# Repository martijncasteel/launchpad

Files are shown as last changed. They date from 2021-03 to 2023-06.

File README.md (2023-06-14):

# push-to-talk
A simple macro keyboard designed for using USB HID protocol.

> Unfortantly I was not able to get the device working as intended. There is nothing wrong with the hardware or the code, it is just something I want I can't do without getting a certification with Microsoft. I did learn a lot, plugging in a USB device will never be the same!

My approach is to use the USB HID protocol in full and specifically the USB HID Telephone pages. The goal is to mute and unmute the microphone on Teams on a laptop, even when teams is not in focus.

```
 BTN0  - flash, end call
 BTN1  - camera toggle on/off
 BTN2  - volume increment
 BTN3  - volume decrement
 BTN4  - volume mute
 BTN5  - microphone mute toggle
 BTN6  - Hold to unmute microphone
```

This repository contains the entire project, [/pcb](https://github.com/martijncasteel/launchpad/tree/main/pcb) contains the schematics and design of the board. I used [Kicad](https://www.kicad.org/) for this. The gerber files and other nessecities for manufacturing are located in the [/assembly](https://github.com/martijncasteel/launchpad/tree/main/assembly) folder.

The board is designed to have six regular 1u keycaps, and one 2u keycap. All use regular cherry mx key switches. The board has an ATmega32u4 with native usb support. The ICSP connector can be used to flash the microcontroller. 

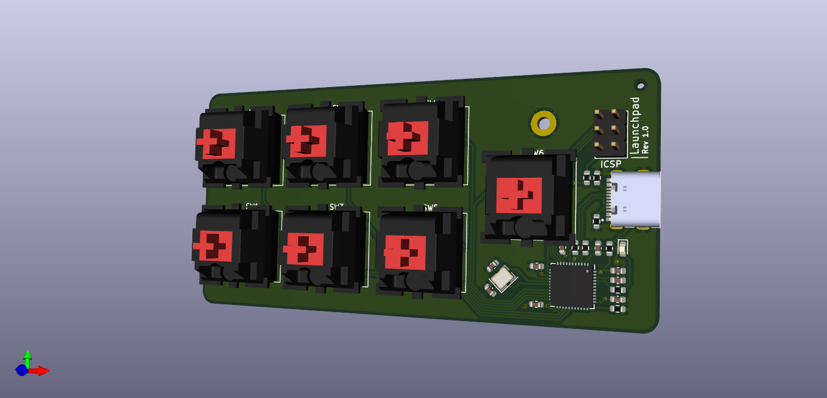
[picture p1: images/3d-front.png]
3D render


The [software](https://github.com/martijncasteel/launchpad/tree/main/code) is written in C and built using avr-gcc. Using avrdude you can flash the microcontroller as well as setting some fuses. In my search on how other have done this, I haven't found a lot of sources on lowlevel programming with USB. To help you further along I added loads of comments. 

<br /><br /><!-- spacing for header -->

## My story so far
During my study I did a lot of software engineering but never went further than using arduino's. So my goal was to learn more about hardware. A lot of youtube videos brought me so far. [Ben Eater](https://youtu.be/wdgULBpRoXk) has some great videos explaining the USB protocol. [Mitch Davis](https://youtu.be/Q2DakPocvfs) goes into more detail about programming Atmega microcontrollers.

Using schematics from arduino I was able to create a schematic quite easily. Of course, also looked at the datasheets to have a better understanding.

After creating the [assembly](https://github.com/martijncasteel/launchpad/tree/main/assembly), I uploaded the files to a pcb manufactorer and also let them populate the board. I had some issues with the USB port since the wrong one was in the BOM. Finally I started [coding](https://github.com/martijncasteel/launchpad/tree/main/code), at first with the arduino IDE. But quickly realised that I wanted to do it from scratch. Down the rabbit hole, I went!

<br /><br /><!-- spacing for header -->

## Where I am now
Well, the hardware went back in a drawer, I'm updating my README and that's it I guess. The buttons declared in the normal consumer control are working; volume up/down, and mute. The toggle camera is somewhat working, however teams just freezes the last frame and is not able to recover from it. More about the implementation in the [code](https://github.com/martijncasteel/launchpad/tree/main/code) directory.

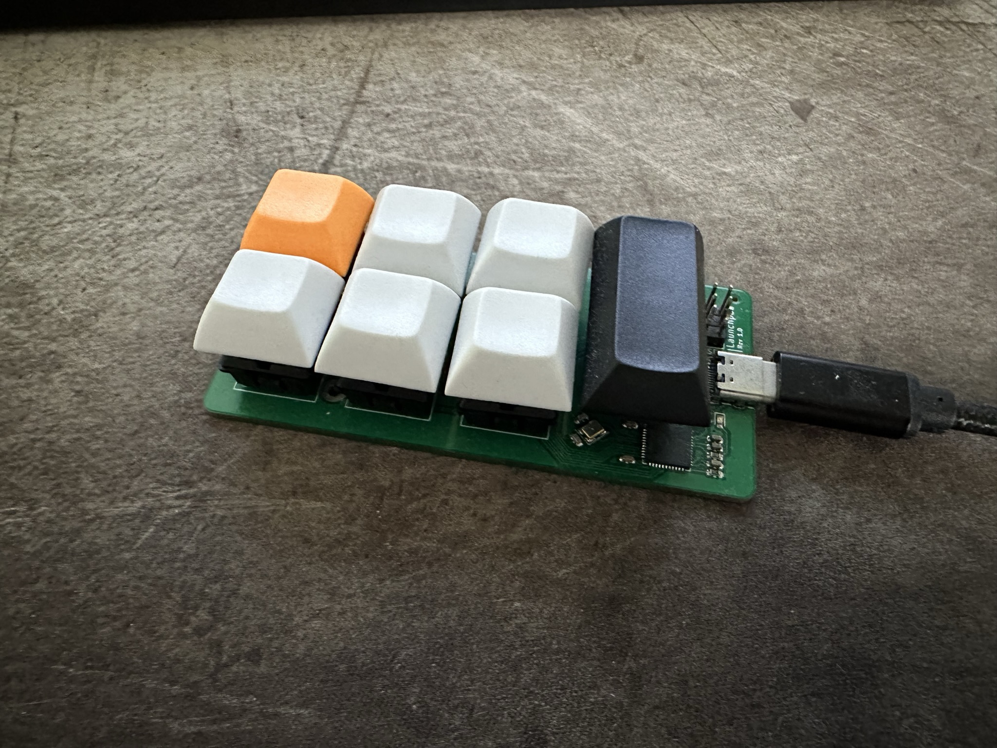
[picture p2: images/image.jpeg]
Launchpad photo


The buttons for the telephone page; mute microphone and flash are not working. The computer receives the commands fine but not actions is take by the OS or teams. It did cross my mind to implement it as a [generic keyboard](https://github.com/martijncasteel/launchpad/commit/3572334c3c04b70ffb8cd755422ddb2e0c5258f0) and use the teams shortcuts. The whole purpose was to be able to mute microsoft without having it in focus, so I scratched that idea. But it will work

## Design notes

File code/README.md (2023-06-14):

# push-to-talk - code

In this README the code directory is explained in more detail. 

## setting up dev environment

```bash
sudo apt update
sudo apt install binutils gcc-avr avr-libc avrdude make
```

The [binary](https://github.com/martijncasteel/launchpad/tree/main/code/bin) can be flashed on the board using the Makefile. The code is far from perfect, and there might be plenty of improvements, feel free to add a pull request! 

```bash
# built intermediates in /build and binary in /bin
# note; changes in header files are not picked up, use make clean
make

# flash to microcontroller
# note; /dev/ttyUSB0 is also the default port, argument can be omitted
make flash PORT=/dev/ttyUSB0

# set fuses on microcontroller
make fuses PORT=/dev/ttyUSB0

# remove intermediates and binary
make clean
```

<br /><!-- spacing for header -->

## USB HID Telephone pages
This approach uses a custom report descriptor defined in [usb.h](https://github.com/martijncasteel/launchpad/tree/main/code/include/usb.h) which is mapped on the pins used by the buttons. For the bigger button, there is some additional code to set either one of the two least significant bits. When the button is pressed the microphone is unmuted, when released the microphone is muted. 

There are more buttons to toggle to mute the microphone and a button to mute the speakers. There are two buttons to increase or decrease the volume, and also a button to hang up the phone. The complete button map is described in [board.h](https://github.com/martijncasteel/launchpad/tree/main/code/include/board.h)

> This is my preferred implementation, it is pretty neat. Unfortunately, it is not working yet since Teams is not supporting the USB HID Telephone pages.
> Microsoft has chosen to only allow certified paying manufacturers to create integrated hardware.

In trying to get it to work I have now created multiple reports with their own report id. Windows works better with volume control in a separate consumer control collection. Windows is also very picky in the byte alignment, you must add padding to get full bytes, otherwise Windows will throw an urb_fuction_abort error.

As a last resort I tried a new feature called [call state management control](https://www.usb.org/sites/default/files/hutrr106-callstatemanagementcontrol_0.pdf). It was actually submitted by Microsoft to the USB organisation and added to the HUT pages. Unfortunatly I wasn't working for me. But I suspect It could be do to my managed laptop. I did not save the code, but there is a nice example in the link above.

<br /><!-- spacing for header -->

## Debugging
After watching loads of [Ben Eater](https://www.youtube.com/watch?v=2lPzTU-3ONI) videos I used a [usb capture](https://wiki.wireshark.org/CaptureSetup/USB) extension for Wireshark. This allowed me to see the communication and the setup progress. There you'll find the first hints why stuff isn't working. In Windows the device manager can give you some more hints, especially the byte alignment is mentioned here, Linux doesn't throw an error if the alignment is off. In my board I did not include any pins for debugging using a wire protocol. This might it a bit tricky in the beginnen but with the single led I made it work.

<br /><!-- spacing for header -->

## Documentation
In [/docs](/martijncasteel/launchpad/tree/main/code/docs) there are several relevant files for using USB HID and the ATMega32u4 microcontroller. Furthermore, there are some links below that have some more information
* https://docs.rs/atmega32u4/0.1.2/atmega32u4/usb/struct.UEINTX.html
* https://ww1.microchip.com/downloads/en/devicedoc/atmel-7766-8-bit-avr-atmega16u4-32u4_datasheet.pdf
* https://github.com/kmani314/ATMega32u4-HID-Keyboard

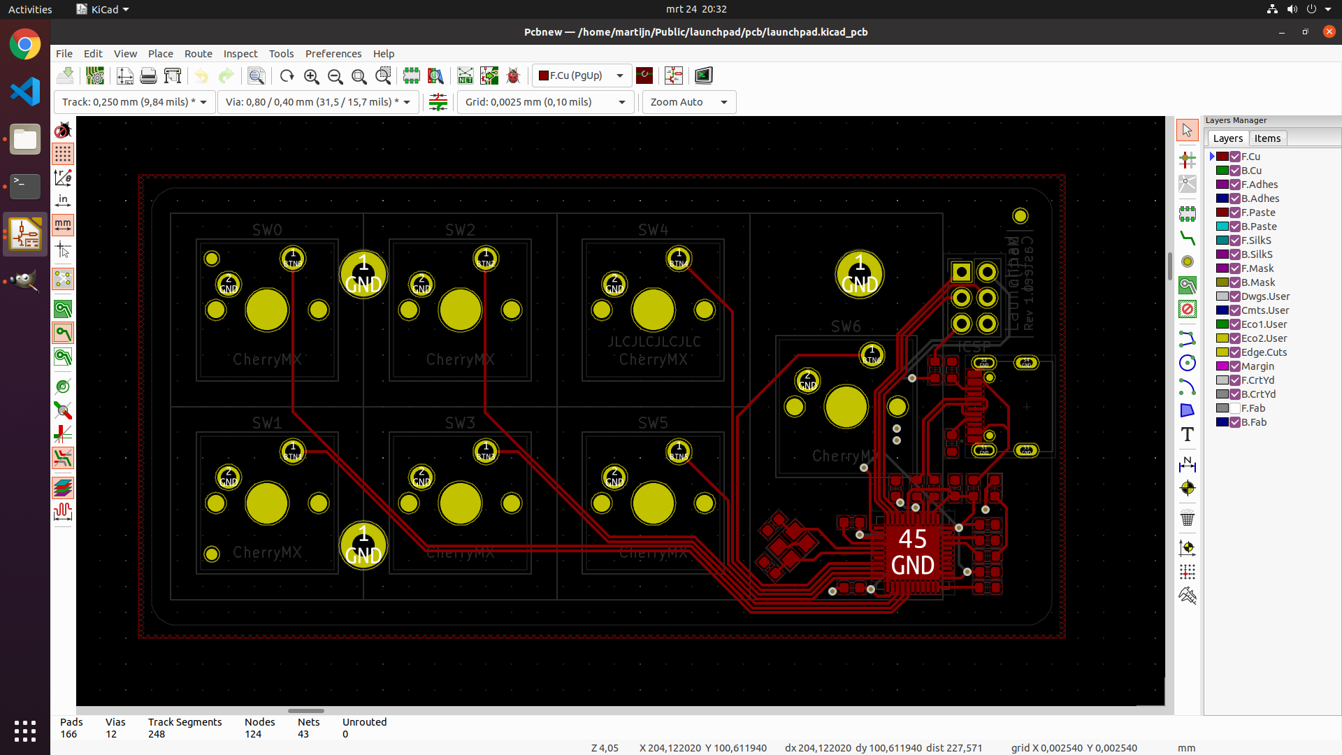
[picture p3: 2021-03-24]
images/f-cu.png

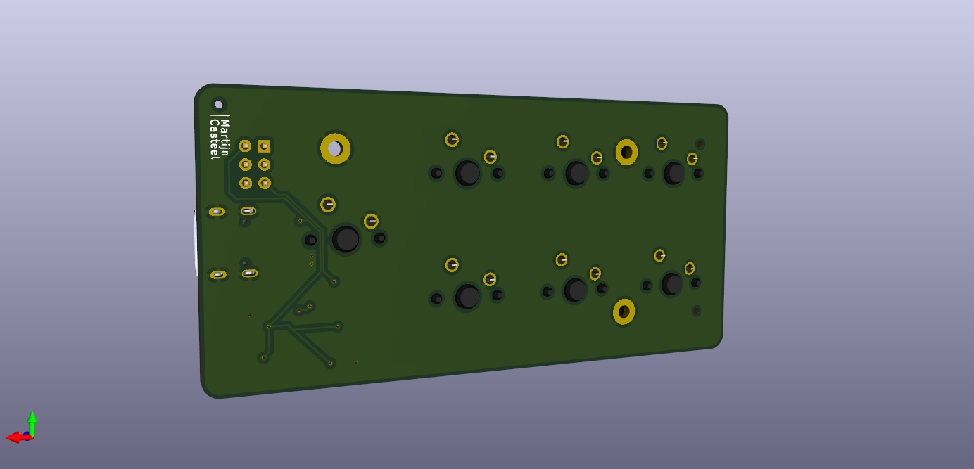
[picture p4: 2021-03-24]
images/3d-back.png

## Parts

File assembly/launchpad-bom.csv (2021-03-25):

Comment | Designator | Footprint | LCSC
1uF | C2 | Capacitor_SMD:C_0603_1608Metric | C15849
0.1uF | C1,C3,C4,C5,C6 | Capacitor_SMD:C_0603_1608Metric | C14663
10uF | C7 | Capacitor_SMD:C_0603_1608Metric | C19702
22pF | C8,C9 | Capacitor_SMD:C_0603_1608Metric | C1653
RED | D2 | LED_SMD:LED_0603_1608Metric | C2286
500mA | F1 | Fuse:Fuse_0603_1608Metric | C261937
TYPE-C-31-M-12 | J1 | Custom:HRO_TYPE-C-31-M-12 | C165948
ICSP | J2 | Connector_PinHeader_2.54mm:PinHeader_2x03_P2.54mm_Vertical
22 | R2,R3 | Resistor_SMD:R_0603_1608Metric | C23345
10K | R1,R4 | Resistor_SMD:R_0603_1608Metric | C25804
1K | R5 | Resistor_SMD:R_0603_1608Metric | C21190
5.1K | R6,R7 | Resistor_SMD:R_0603_1608Metric | C23186
CherryMX | SW0,SW1,SW2,SW3,SW4,SW5 | Button_Switch_Keyboard:SW_Cherry_MX_1.00u_PCB
CherryMX | SW6 | Custom:SW_Cherry_MX_2.00u_Vertical_PCB_unsupported
ATmega32U4-MUR | U1 | Package_DFN_QFN:QFN-44-1EP_7x7mm_P0.5mm_EP5.2x5.2mm | C45874
Crystal_GND24_Small | Y1 | Crystal:Crystal_SMD_3225-4Pin_3.2x2.5mm | C13738

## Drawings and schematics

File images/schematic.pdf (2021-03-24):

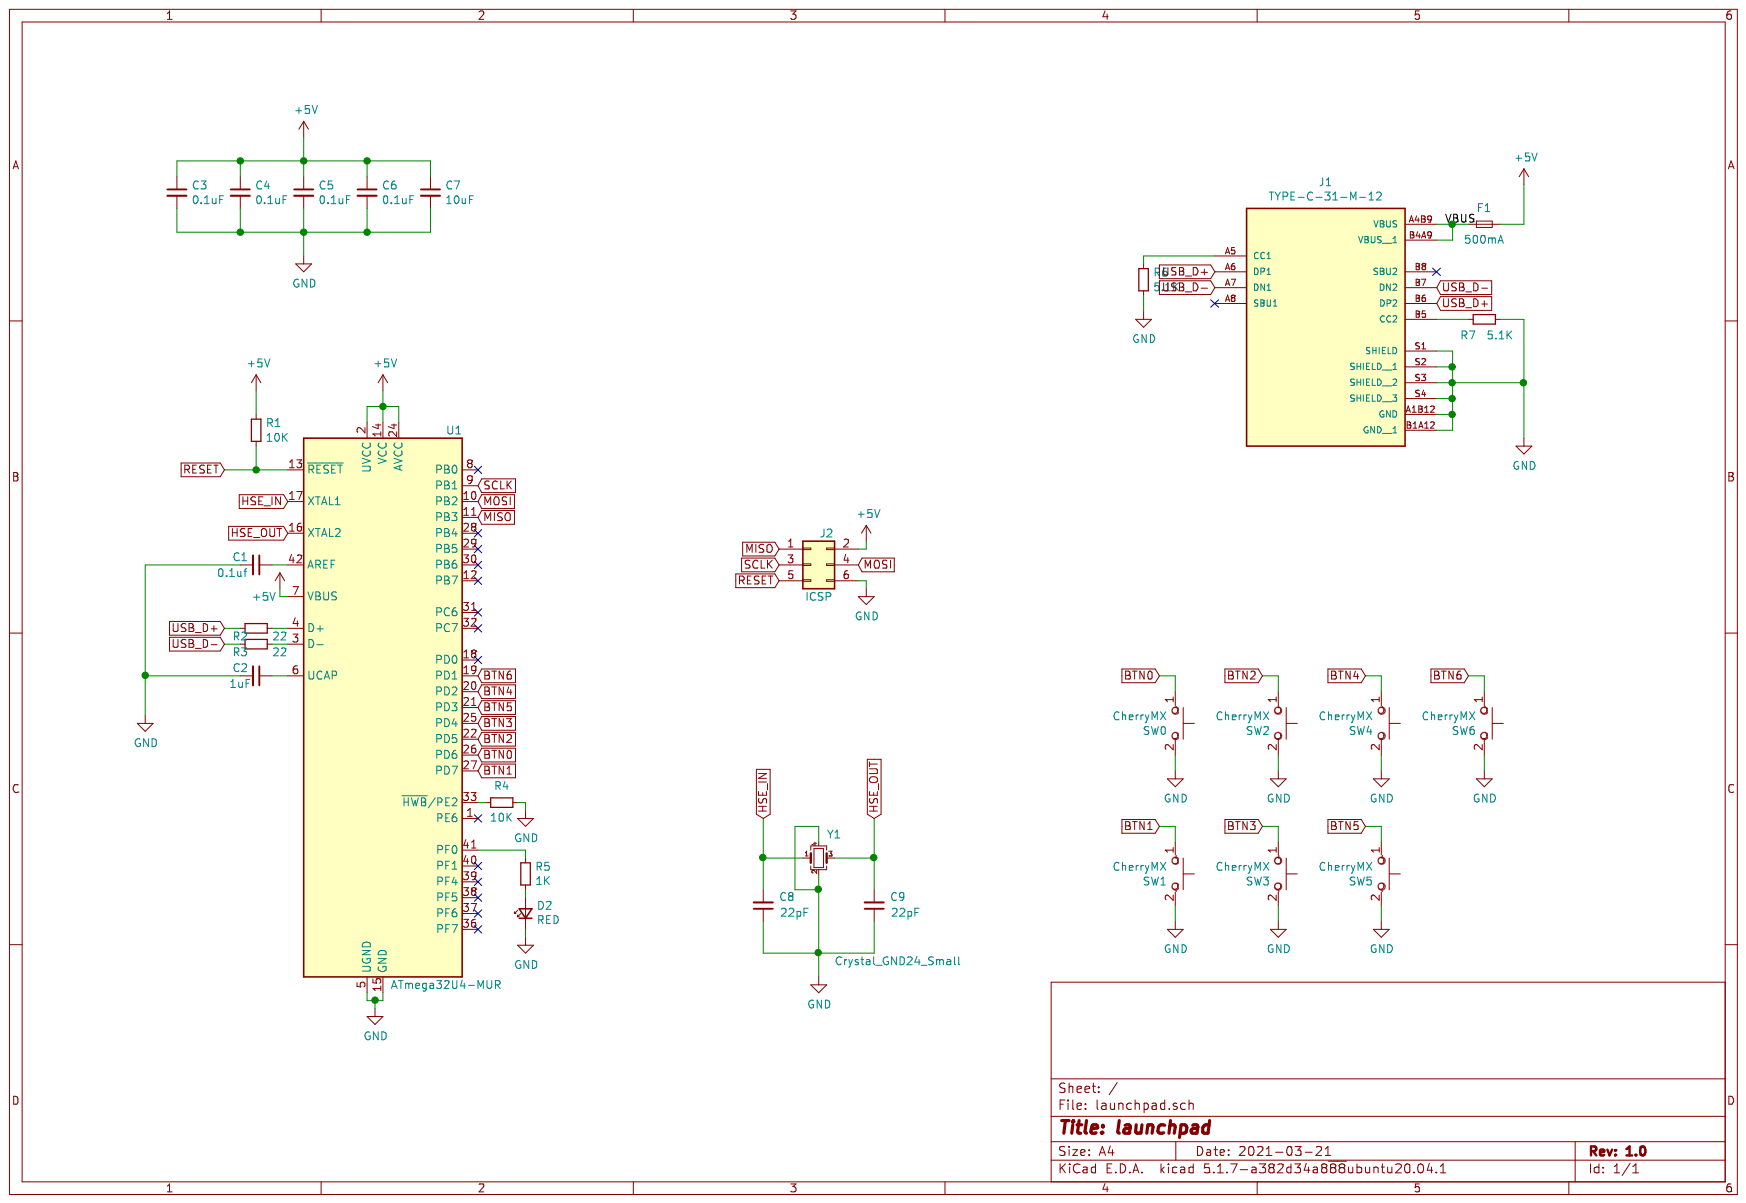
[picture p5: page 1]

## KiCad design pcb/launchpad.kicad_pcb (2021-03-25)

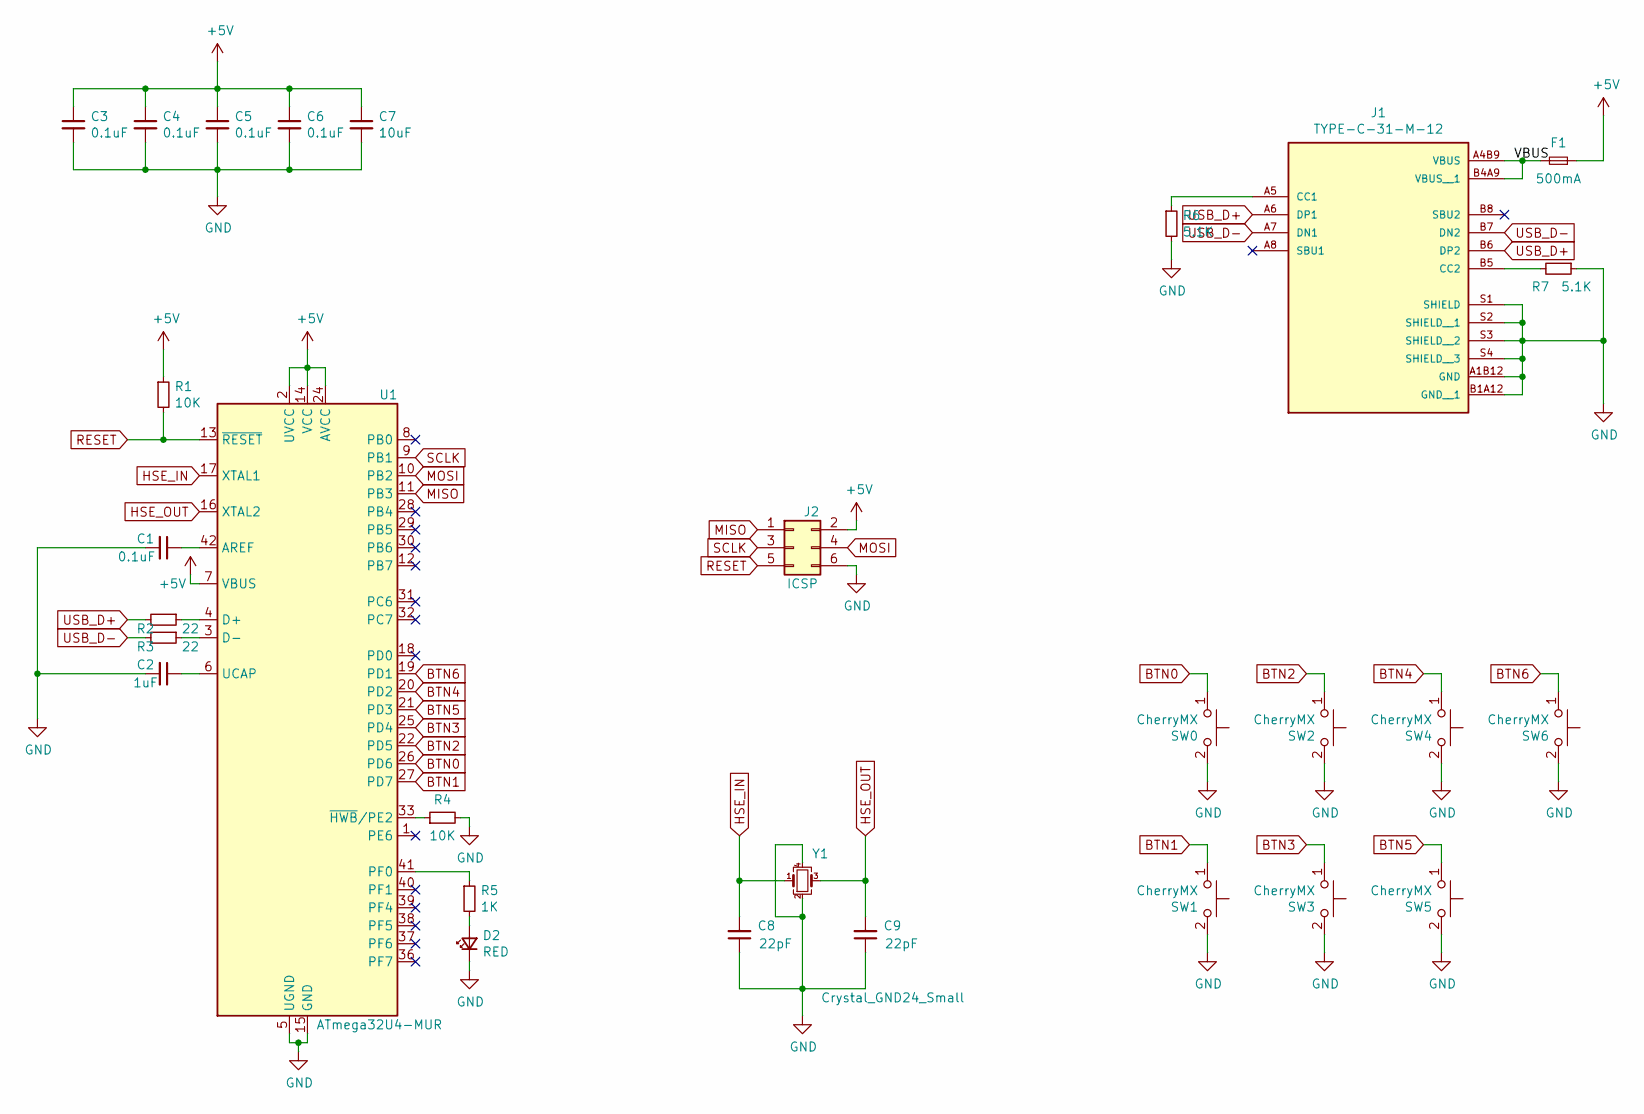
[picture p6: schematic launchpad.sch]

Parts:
C1, C3, C4, C5, C6: 0.1uF; C_0603_1608Metric; LCSC C14663
C2: 1uF; C_0603_1608Metric; LCSC C15849
C7: 10uF; C_0603_1608Metric; LCSC C19702
C8, C9: 22pF; C_0603_1608Metric; LCSC C1653
D2: RED; LED_0603_1608Metric; LCSC C2286
F1: 500mA; Fuse_0603_1608Metric; LCSC C261937
J1: TYPE-C-31-M-12; HRO_TYPE-C-31-M-12; PARTREV A; LCSC C165948
J2: ICSP; PinHeader_2x03_P2.54mm_Vertical
R1, R4: 10K; R_0603_1608Metric; LCSC C25804
R2, R3: 22; R_0603_1608Metric; LCSC C23345
R5: 1K; R_0603_1608Metric; LCSC C21190
R6, R7: 5.1K; R_0603_1608Metric; LCSC C23186
SW0, SW1, SW2, SW3, SW4, SW5: CherryMX; SW_Cherry_MX_1.00u_PCB
SW6: CherryMX; SW_Cherry_MX_2.00u_Vertical_PCB_unsupported
U1: ATmega32U4-MUR; QFN-44-1EP_7x7mm_P0.5mm_EP5.2x5.2mm; LCSC Part # C45874
Y1: Crystal_GND24_Small; Crystal_SMD_3225-4Pin_3.2x2.5mm; LCSC C13738

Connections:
+5V: C3.1, C4.1, C5.1, C6.1, C7.1, F1.1, J2.2, R1.1, U1.2 (UVCC), U1.7 (VBUS), U1.14 (VCC), U1.24 (AVCC), U1.34 (VCC), U1.44 (AVCC)
/VBUS: F1.2, J1.A4B9 (VBUS), J1.B4A9 (VBUS__1)
BTN0: SW0.1, U1.26 (PD6)
BTN1: SW1.1, U1.27 (PD7)
BTN2: SW2.1, U1.22 (PD5)
BTN3: SW3.1, U1.25 (PD4)
BTN4: SW4.1, U1.20 (PD2)
BTN5: SW5.1, U1.21 (PD3)
BTN6: SW6.1, U1.19 (PD1)
GND: C1.2, C2.2, C3.2, C4.2, C5.2, C6.2, C7.2, C8.1, C9.1, D2.1 (K), J1.A1B12 (GND), J1.B1A12 (GND__1), J1.S1 (SHIELD), J1.S2 (SHIELD__1), J1.S3 (SHIELD__2), J1.S4 (SHIELD__3), J2.6, R4.2, R6.2, R7.1, SW0.2, SW1.2, SW2.2, SW3.2, SW4.2, SW5.2, SW6.2, U1.5 (UGND), U1.15 (GND), U1.23 (GND), U1.35 (GND), U1.43 (GND), U1.45 (GND), Y1.2, Y1.4; also elsewhere on the board
HSE_IN: C8.2, U1.17 (XTAL1), Y1.1
HSE_OUT: C9.2, U1.16 (XTAL2), Y1.3
MISO: J2.1, U1.11 (PB3)
MOSI: J2.4, U1.10 (PB2)
unnamed: C1.1, U1.42 (AREF)
unnamed: C2.1, U1.6 (UCAP)
unnamed: D2.2 (A), R5.2
unnamed: J1.A5 (CC1), R6.1
unnamed: J1.B5 (CC2), R7.2
unnamed: R2.1, U1.4 (D+)
unnamed: R3.1, U1.3 (D-)
unnamed: R4.1, U1.33 (~HWB~/PE2)
unnamed: R5.1, U1.41 (PF0)
RESET: J2.5, R1.2, U1.13 (~RESET)
SCLK: J2.3, U1.9 (PB1)
USB_D+: J1.A6 (DP1), J1.B6 (DP2), R2.2
USB_D-: J1.A7 (DN1), J1.B7 (DN2), R3.2

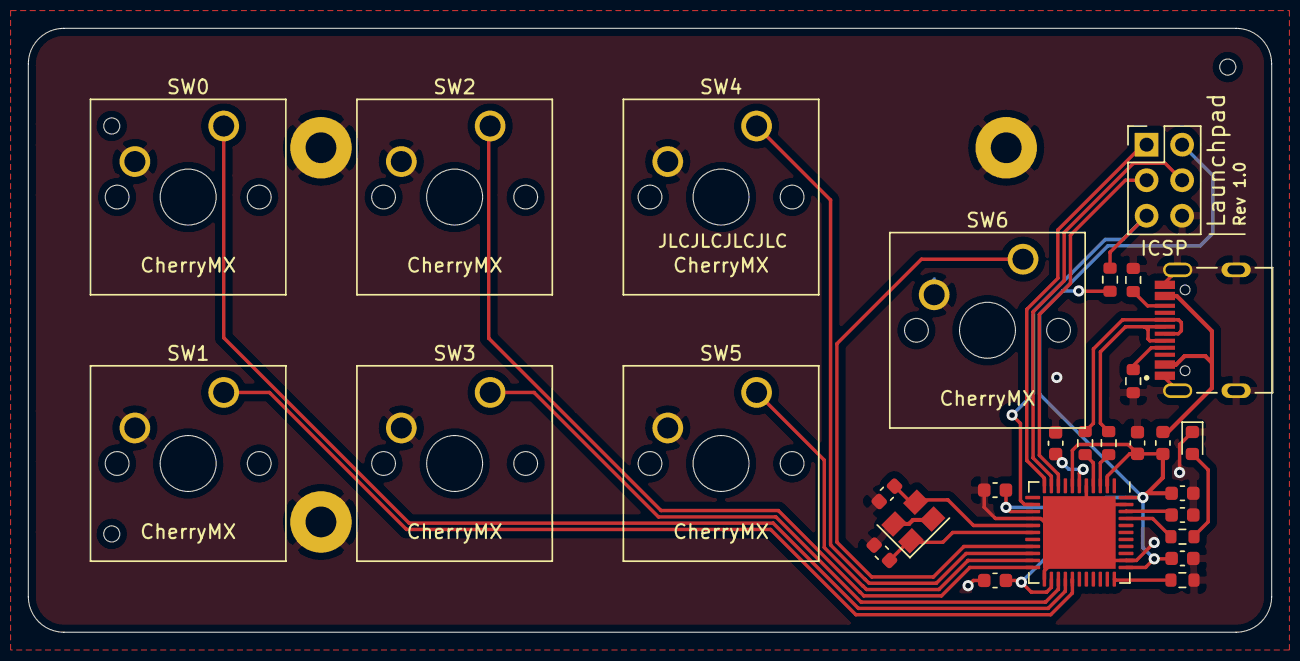
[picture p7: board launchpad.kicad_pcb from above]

Board: 2 copper layers, 88.9 x 43.2 mm, 32 parts (0 on the bottom side), 27 nets.

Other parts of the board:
H1, H2, H3: MountingHole_Pad; MountingHole_2.2mm_M2_Pad

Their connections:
GND: H1.1, H2.1, H3.1; also elsewhere on the board

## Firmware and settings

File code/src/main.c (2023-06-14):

/**
 * @name launchpad
 * @file main.c
 * 
 * @brief Mini keypad acts a usb hid device to control default functions
 * @link https://github.com/martijncasteel/launchpad
 * 
 * During covid I wanted to mute my mic with a simple key press. Unfortunatly I
 * am not allowed to write own drivers to solve this problem on the computer side.
 * 
 * Next to that I found it very interesting to design and use a custom pcb made 
 * somewhere in china. I learned lots of stuff doing this project such as pcb design,
 * revisited c and started using avr-gcc and avrdude. Ben Eater had some cool videos
 * about the USB protocol and learned lots on USB as well. 
 * 
 * Let's say, plugging in a USB device will never be the same! 
 * 
 * @author Martijn Casteel
 * @date 2022-12-22
 */

#define __ATmega32U4__
#define F_CPU 16000000UL

#include "board.h"
#include "usb.h"

#include <avr/io.h>
#include <util/delay.h>

int main()
{

  PORTD = 0xff;                 // pull up resistors, low is pressed
  DDRD &= 0x00;                 // data direction to read of PORTD
  
  DDRF |= (1 << LED);           // Make pin 23 / PORTF0 be an output

  data_t* data = usb_init();  // initialize usb connection
  uint8_t counter = 0;          // counter to check buttons once every 50 ms

  while(1) {

    if (counter % 50 == 0) {
      check_buttons(&(data->dout));
      counter = 0;
    }

    // control led
    animate_led(&(data->din));
    
    counter++;
    _delay_ms(1); 
  }

  return 0;
}

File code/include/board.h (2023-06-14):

/**
 * @file board.h
 * @brief Header file contains the layout of the board
 * 
 * @author Martijn Casteel
 * @date 2022-12-22
*/

#include <avr/io.h>

#ifndef BOARD_H
#define BOARD_H

/**
 * Layout of the board, all buttons are connected to the D 
 * register (PORTD). Should have made this mapping way 
 * simpler, revision 2 perhaps?
 * 
 * There is a single led on PORTF0.
 * 
 *  +------+------+------+------+
 *  | BTN0 | BTN2 | BTN4 |      |
 *  +------+------+------+ BTN6 |
 *  | BTN1 | BTN3 | BTN5 |      |
 *  +------+------+------+------+
 * 
 */

#define BTN0 PIND6
#define BTN1 PIND7
#define BTN2 PIND5
#define BTN3 PIND4
#define BTN4 PIND2
#define BTN5 PIND3
#define BTN6 PIND1

/**
 * BTN0  - flash
 * BTN1  - camera toggle
 * BTN2  - volume increment
 * BTN3  - volume decrement
 * BTN4  - volume mute
 * BTN5  - microphone mute toggle
 * BTN6  - Hold to unmute microphone
 * 
 * PIND0 - 
 * PIND1 - hold to unmute microphone
 * PIND2 - volume mute
 * PIND3 - microphone mute toggle 
 * PIND4 - volume decrement
 * PIND5 - volume increment
 * PIND6 - flash
 * PIND7 - camera toggle 
 */

#define LED PORTF0

int8_t check_buttons(uint16_t* dout);
int8_t animate_led(uint8_t* din);

#endif

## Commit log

2021-03-03 Created a first schematic with ESD protection, might remove it
    [marco-keyboard.kicad_pcb, marco-keyboard.sch]
2021-03-20 Second version 0.2?
    [marco-keyboard.kicad_pcb, marco-keyboard.sch]
2021-03-21 First version almost done
    [marco-keyboard.kicad_pcb, marco-keyboard.sch]
2021-03-21 Created some files
    [marco-keyboard-B_Cu.gbr, marco-keyboard-B_Mask.gbr, marco-keyboard-B_Paste.gbr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]
2021-03-21 Fixed some things on the bom
    [marco-keyboard.sch]
2021-03-23 This looks like a good version
    [marco-keyboard.kicad_pcb, marco-keyboard.sch]
2021-03-24 So made the buttons active low. And found that I used the wrong ICSP header
    [launchpad.kicad_pcb, launchpad.sch]
2021-03-24 Updated pinheader to appropiate size
    [launchpad-B_Cu.gbr, launchpad-B_Mask.gbr, launchpad-B_Paste.gbr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]
2021-03-25 Order is completed
    [launchpad-B_Cu.gbr, launchpad-B_Mask.gbr, launchpad-B_Paste.gbr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]
2021-03-25 Added some ignored files
    [launchpad-bom.csv, launchpad-footprint-positions.csv]
2022-11-07 kicad additional files
2022-11-20 Added fuses to atleast use the external crystal at 16MHz
2022-12-27 Added some comments, implemented VBUS interrupt
2022-12-29 Implemented logic for push-to-talk button, improved data register
2022-12-29 received a pid from microchip
2023-05-06 Added a place for workaround using teams shortcuts
    [board.h, main.c]
2023-05-07 Described the button layout
2023-05-07 Created a first version with teams shortcuts, next testing
    [board.h, main.c]
2023-05-14 Implemented a basic keyboard which happens to press teams shortcuts
    [board.h, main.c]
2023-06-14 Started working on the LED page
